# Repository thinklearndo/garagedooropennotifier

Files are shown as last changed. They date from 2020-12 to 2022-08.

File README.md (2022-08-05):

# garagedooropennotifier
A nodemcu project to notifiy users when the garage door gets left open.

For assembling the kit, see the [HardwareAssembly](https://github.com/thinklearndo/garagedooropennotifier/blob/main/HardwareAssembly.md)

For a 3d printable enclosure see the folder [3d_printer_files](https://github.com/thinklearndo/garagedooropennotifier/tree/main/3d_printer_files)

Then setup the software as specified in the [software setup](https://github.com/thinklearndo/garagedooropennotifier/blob/main/SoftwareSetup.md).

Kicad board files are in the boardfiles directory.

## OLED Raspberry Pi garage door state

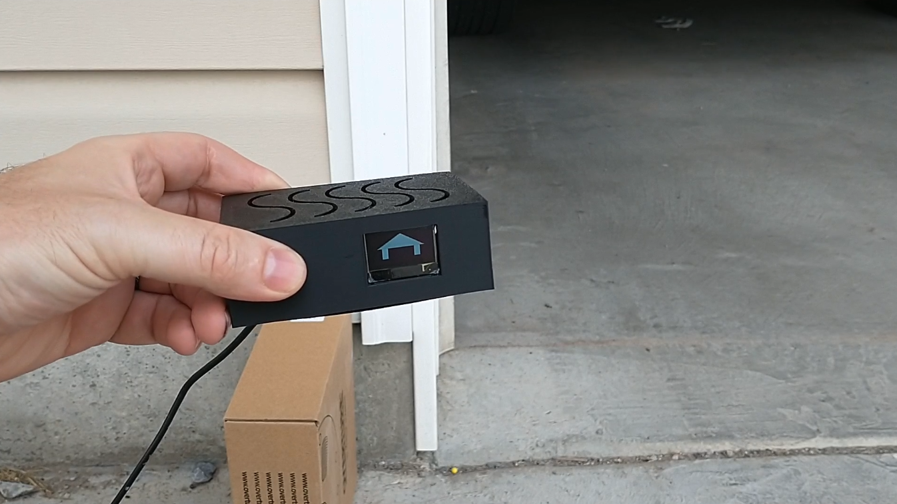
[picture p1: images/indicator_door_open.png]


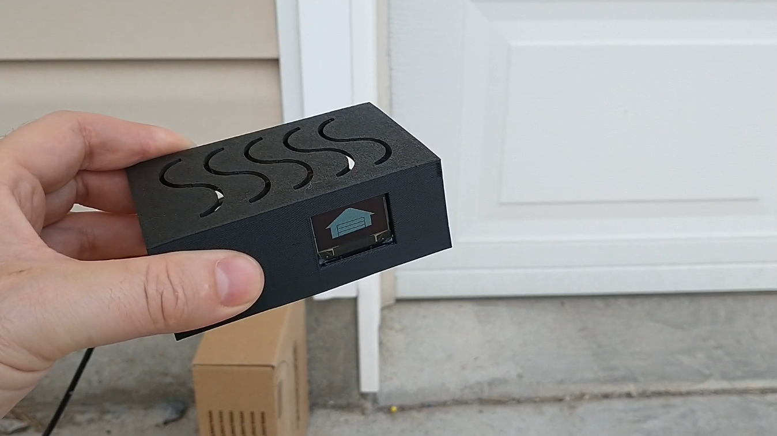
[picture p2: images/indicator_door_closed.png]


To setup a Raspberry Pi + OLED garage door state indicator, check out the [indicator setup document](docs/oledsetup.md).

[See it in action.](https://youtu.be/mj3vsc2727k)

## Troubleshooting

To verify the nodejs server is working correctly, send a get request using a web browser to the server itself, by doing something like:
```
http://<nodejs server ip address>:3000/garageAlert?doorState=1&doorId=0
```
where ```<nodejs server ip address>``` is the address of the server running the nodejs program.

The web browser should have this kind of response:
```
garage door alert received
```
Then after 5 minutes has passed an email should be sent to the specified email address.

If the web browser doesn't get the expected response, verify the ip address of the server and that the nodejs program is running.

If an email is not sent, verify the email settings in the app.js file.

To verify the nodemcu is working correctly, take the cover off and remove a battery to power it off. Then with the garage door closed, insert the battery but leave the cover off. Open the garage door enough that the device is horizontal. Watch the led indicator for the nodemcu, it should blink blue to show it has turned on. Check the console for the nodejs server, there should be a log with this message:
```
garage alert request received
```

If the nodemcu does not turn on, check that the tilt switch is installed correctly.

If the nodemcu does turn on but no message is logged, check the wifi settings and ip address of the firmware that was uploaded to nodemcu.

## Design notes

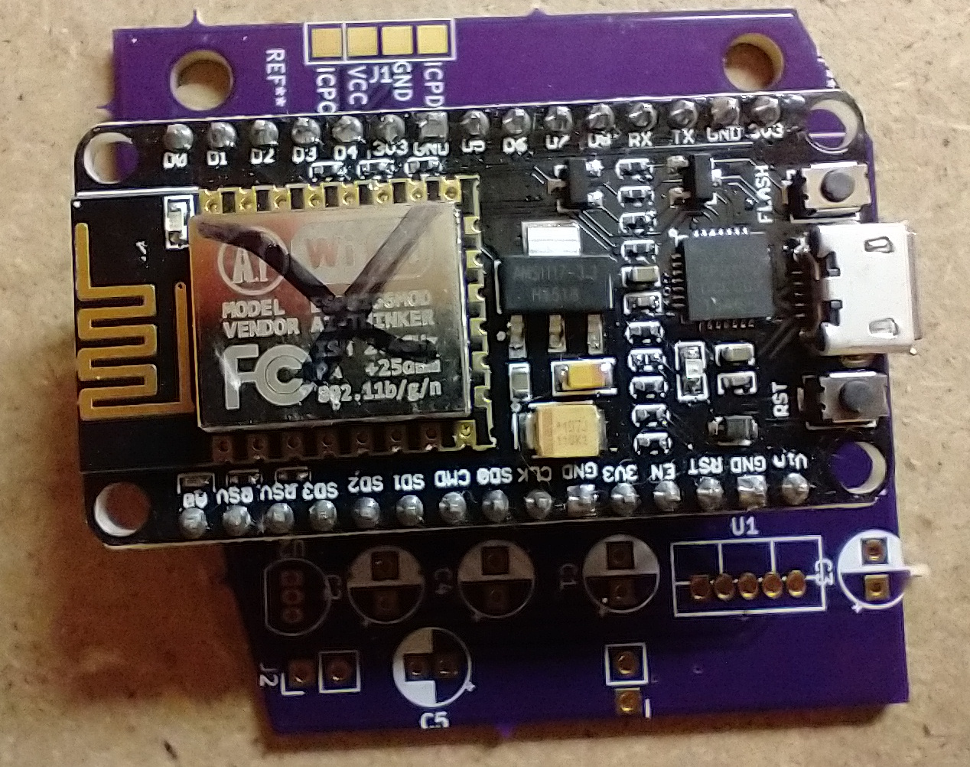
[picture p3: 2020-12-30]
images/nodemcu_inserted.jpg

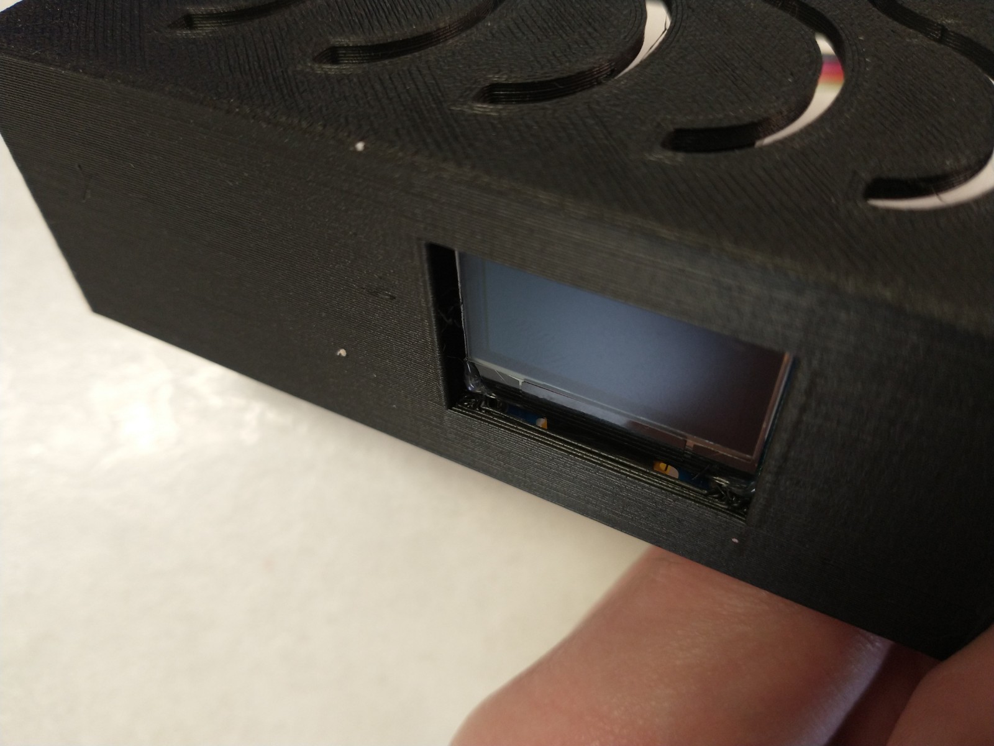
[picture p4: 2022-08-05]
images/oled_front.jpg

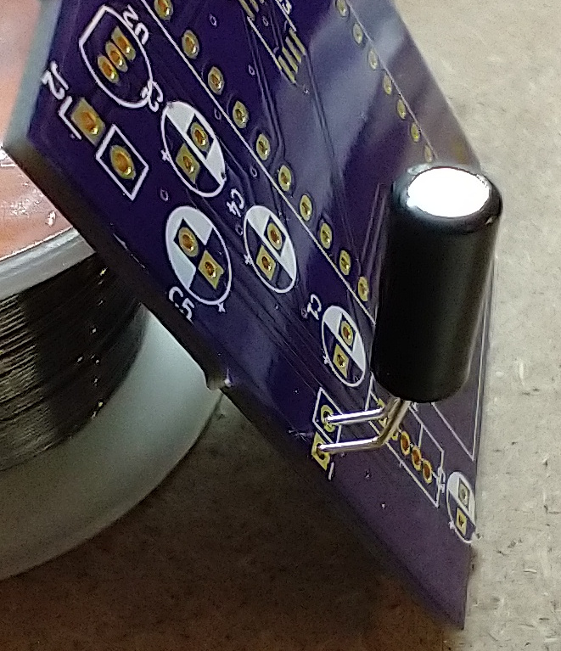
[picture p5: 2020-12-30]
images/tilt_switch_45.jpg

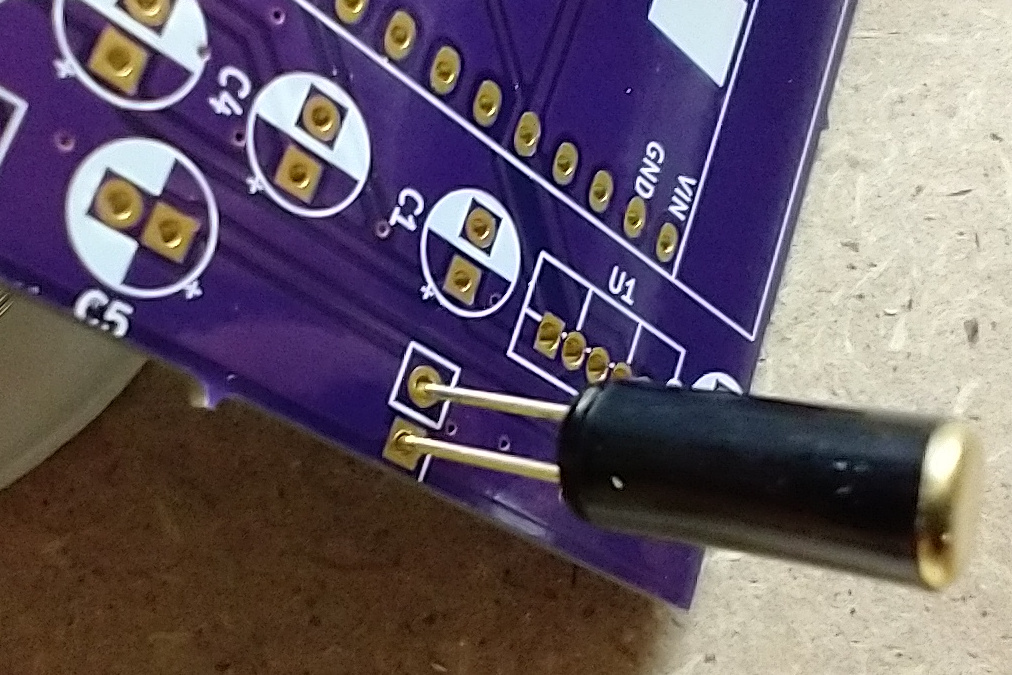
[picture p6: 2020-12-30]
images/tilt_switch_orientation.jpg

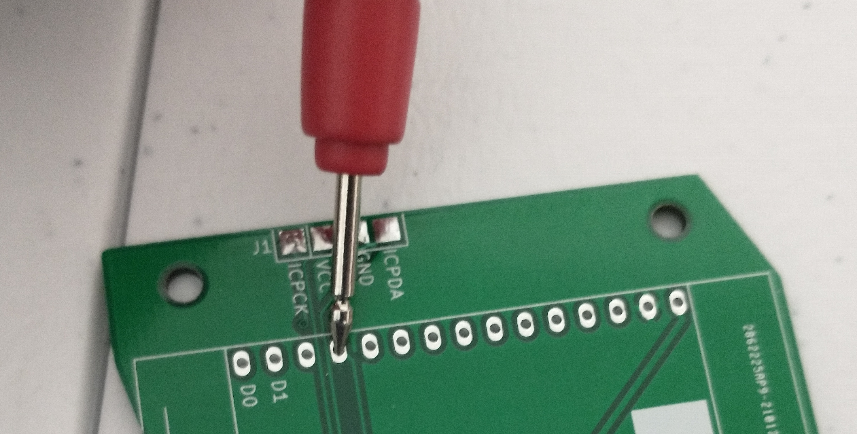
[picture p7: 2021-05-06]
images/positive_pin_4.jpg

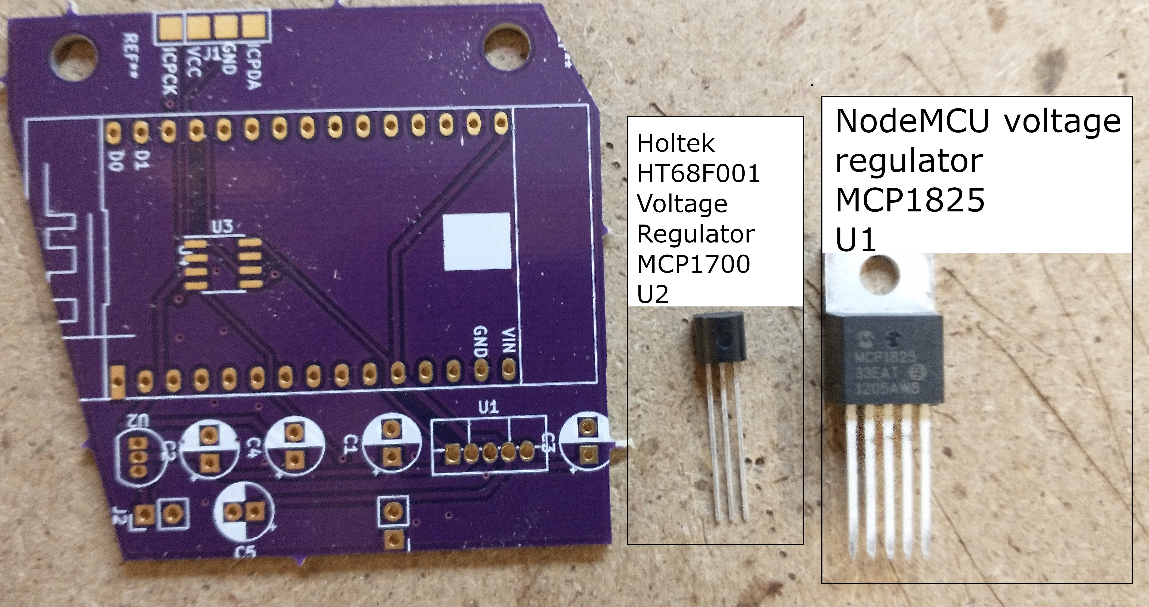
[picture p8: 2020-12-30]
images/voltage_regulators.jpg

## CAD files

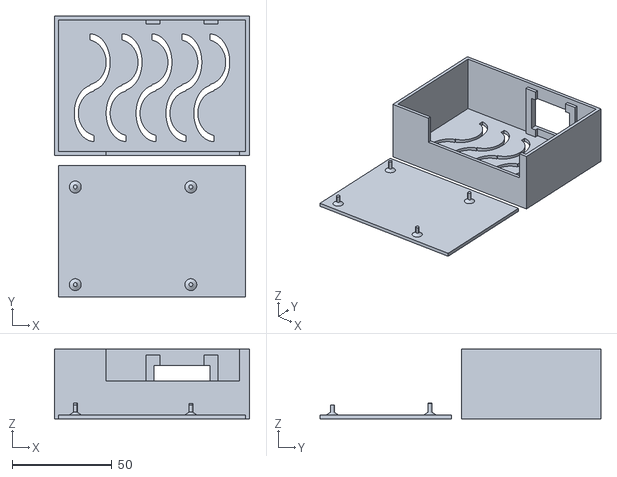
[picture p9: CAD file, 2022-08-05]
3d_printer_files/pi_oled_case_top_and_bottom.stl
98.0 x 141.0 x 35.0

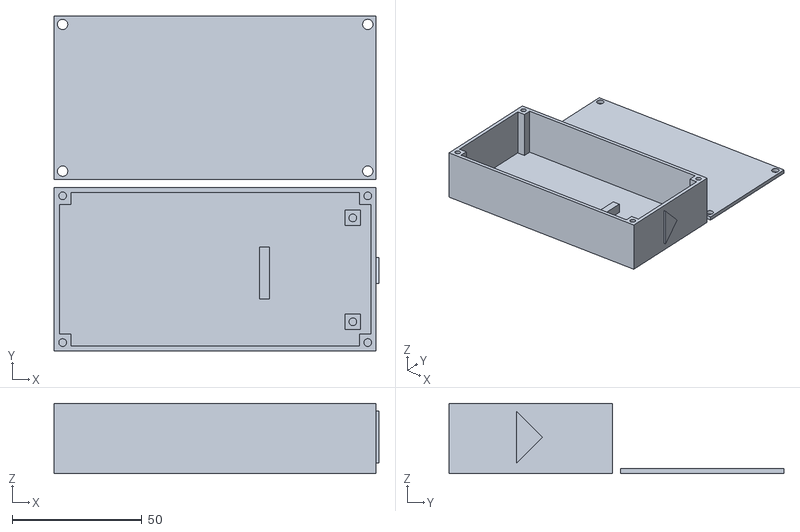
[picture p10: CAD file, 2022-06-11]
3d_printer_files/garagedoor box v1_withArrow.stl
125.0 x 129.0 x 27.0

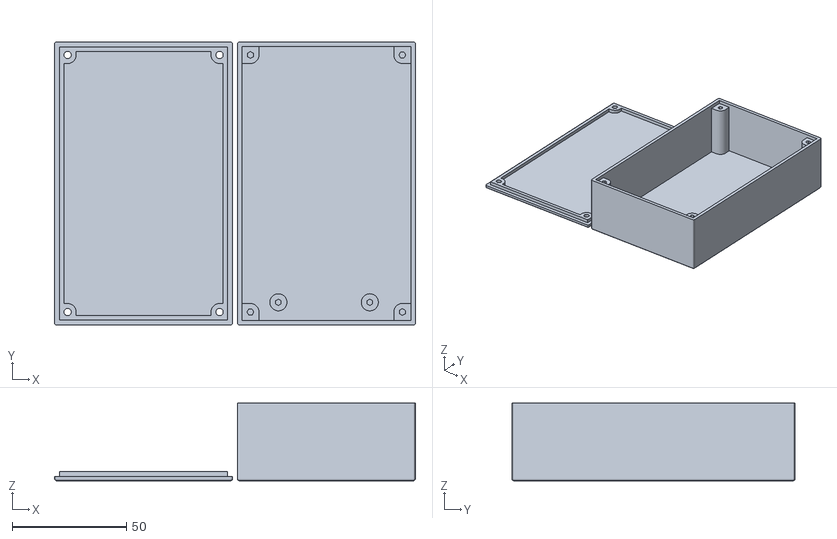
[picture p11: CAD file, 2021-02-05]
3d_printer_files/project_box_screws_garageDoorOpenNotifier.stl
158.0 x 124.0 x 34.0

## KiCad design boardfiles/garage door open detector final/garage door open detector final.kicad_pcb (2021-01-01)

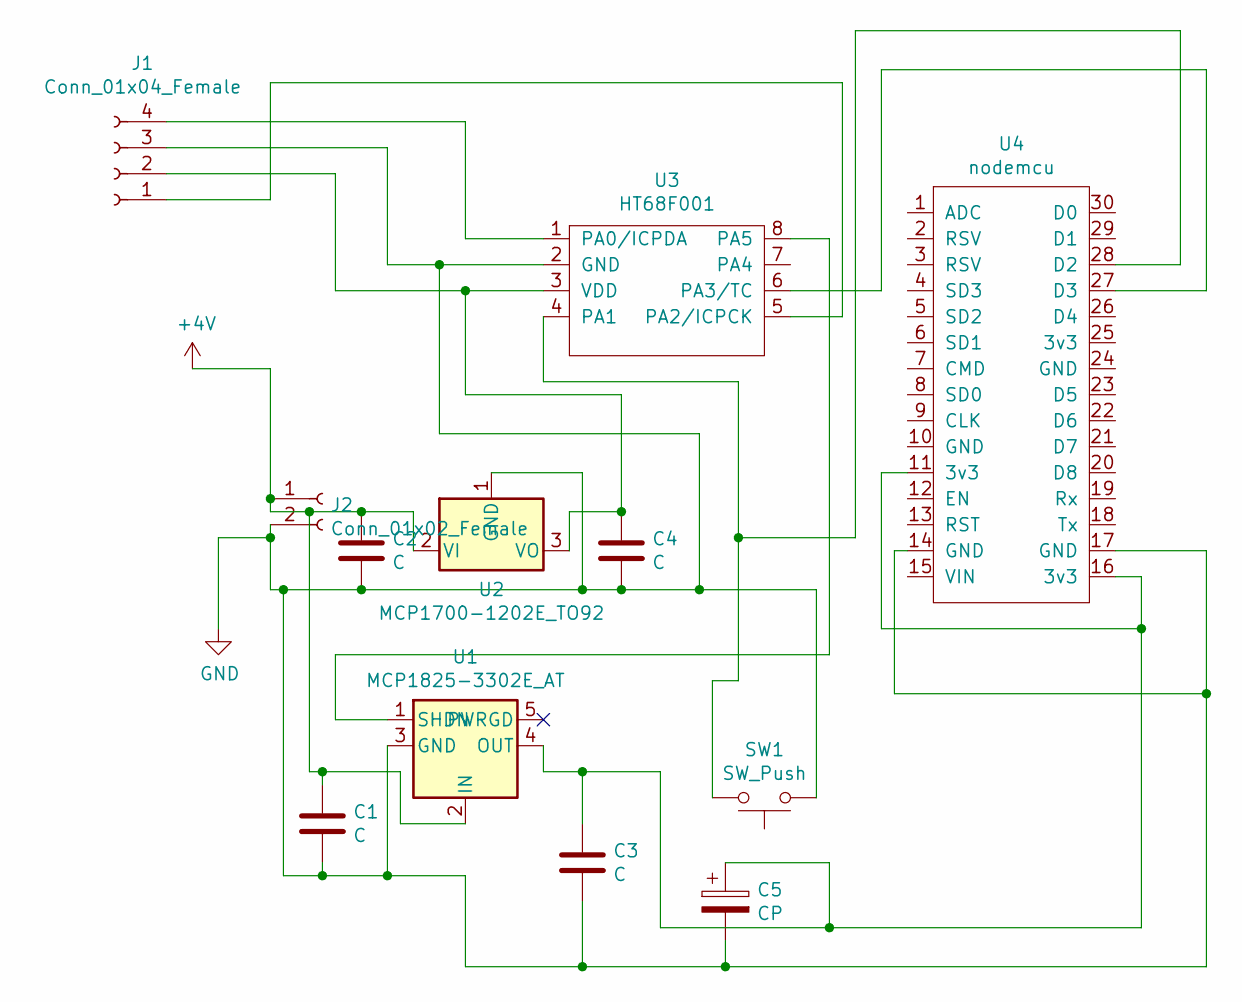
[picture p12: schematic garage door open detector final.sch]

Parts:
C1, C2, C3, C4: C; CP_Radial_D5.0mm_P2.50mm
C5: CP; CP_Radial_D5.0mm_P2.00mm
J1: Conn_01x04_Female; 4_pin_2.54pitch
J2: Conn_01x02_Female; PinHeader_1x02_P2.54mm_Vertical
SW1: SW_Push; PinHeader_1x02_P2.54mm_Vertical
U1: MCP1825-3302E_AT; TO-220F-5_Vertical
U2: MCP1700-1202E_TO92; TO-92_Inline
U3: HT68F001; SOIC-8_3.9x4.9mm_P1.27mm
U4: nodemcu; DIP-30_900_ELL

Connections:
+4V: C1.1, C2.1, J2.1, U1.2 (IN), U2.2 (VI)
GND: C1.2, C2.2, C3.2, C4.2, C5.2, J1.3, J2.2, SW1.1, U1.3 (GND), U2.1 (GND), U3.2 (GND), U4.14 (GND), U4.17 (GND)
unnamed: C3.1, C5.1, U1.4 (OUT), U4.11 (3v3), U4.16 (3v3)
unnamed: C4.1, J1.2, U2.3 (VO), U3.3 (VDD)
unnamed: J1.1, U3.5 (PA2/ICPCK)
unnamed: J1.4, U3.1 (PA0/ICPDA)
unnamed: SW1.2, U3.4 (PA1), U4.28 (D2)
unnamed: U1.1 (SHDN), U3.8 (PA5)
unnamed: U3.6 (PA3/TC), U4.27 (D3)

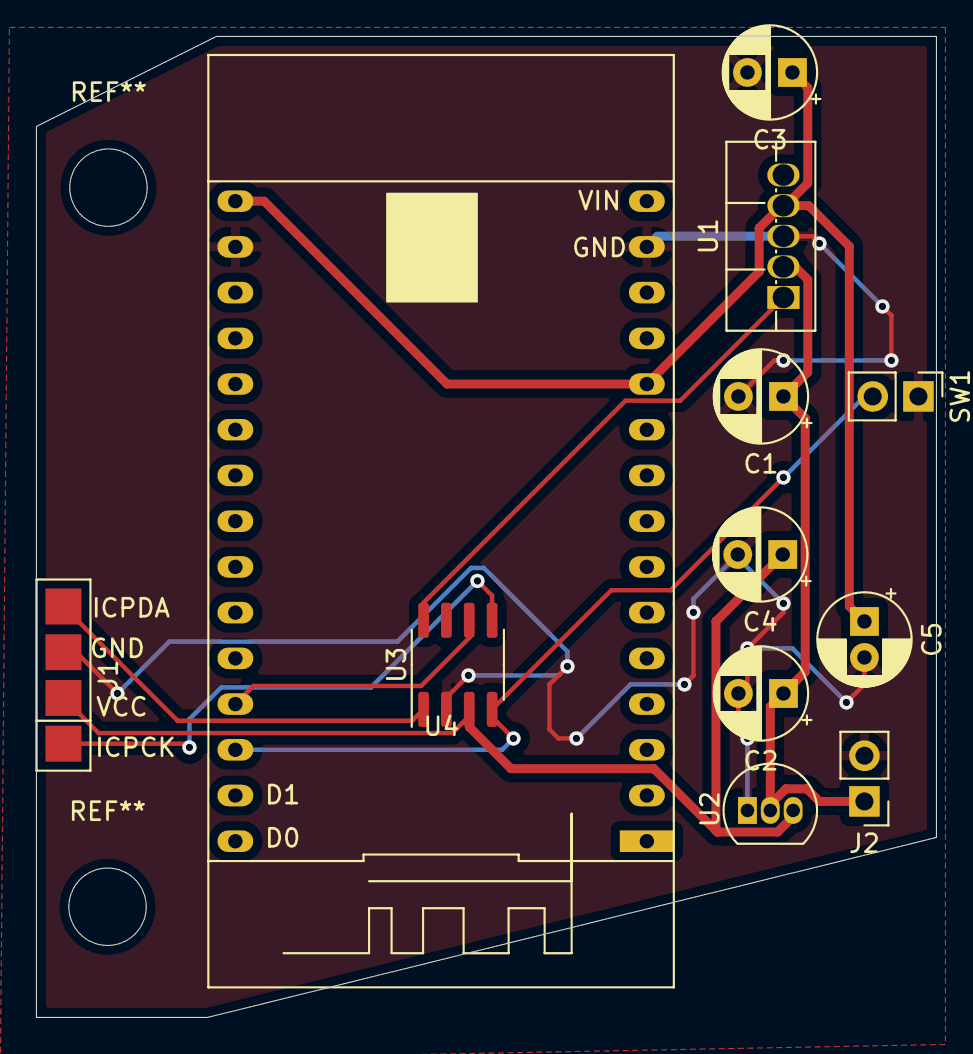
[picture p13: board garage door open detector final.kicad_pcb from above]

Board: 2 copper layers, 50.0 x 54.5 mm, 12 parts (0 on the bottom side), 9 nets.

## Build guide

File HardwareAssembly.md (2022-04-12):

# Hardware Assembly

## Additional items needed.

Phillips screw driver

3x AA batteries

## Program and insert the NodeMCU

Upload the program for the NodeMCU according to the [software instructions](https://github.com/thinklearndo/garagedooropennotifier/blob/main/SoftwareSetup.md). Then insert it into the headers.

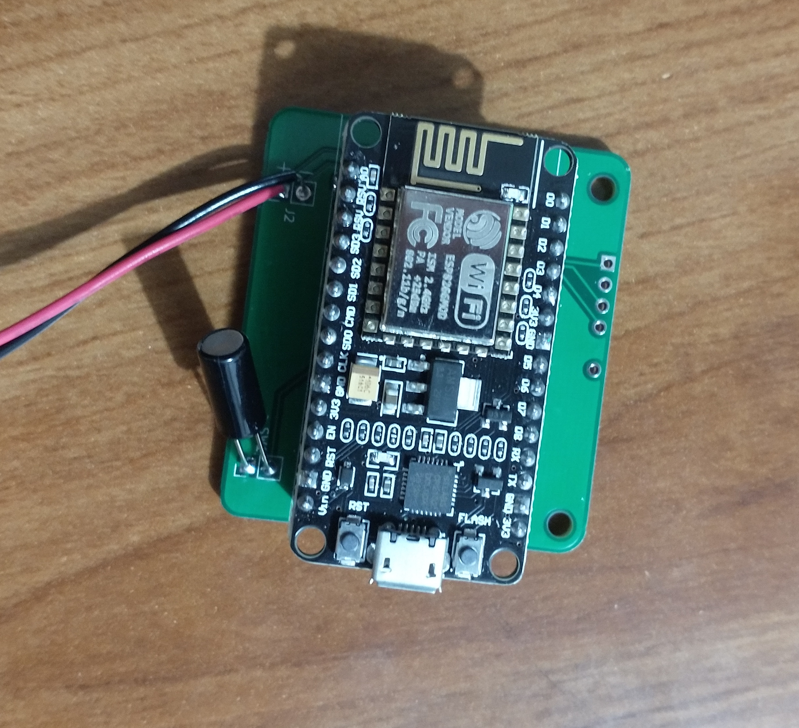
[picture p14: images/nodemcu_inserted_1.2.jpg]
Nodemcu inserted


## Screw the circuit board into the case

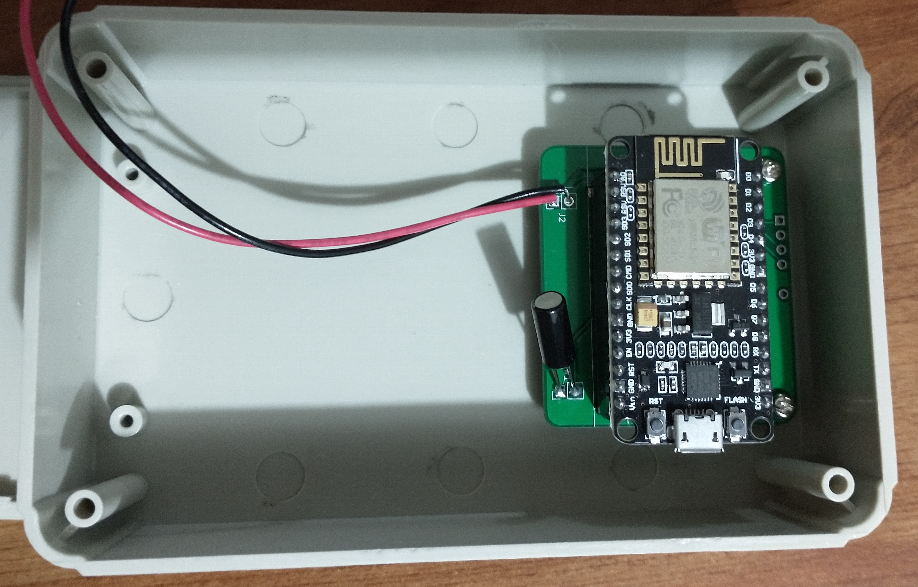
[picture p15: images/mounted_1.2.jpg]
board screwed in


## Put hook and latch material on battery holder and inside case

Get the smaller patch of hook and latch material to put one side on the back of the battery holder and the other side inside the case to the left of the circuit board. Press the battery holder firmly into the box and make sure the hook and latch material is connected well.

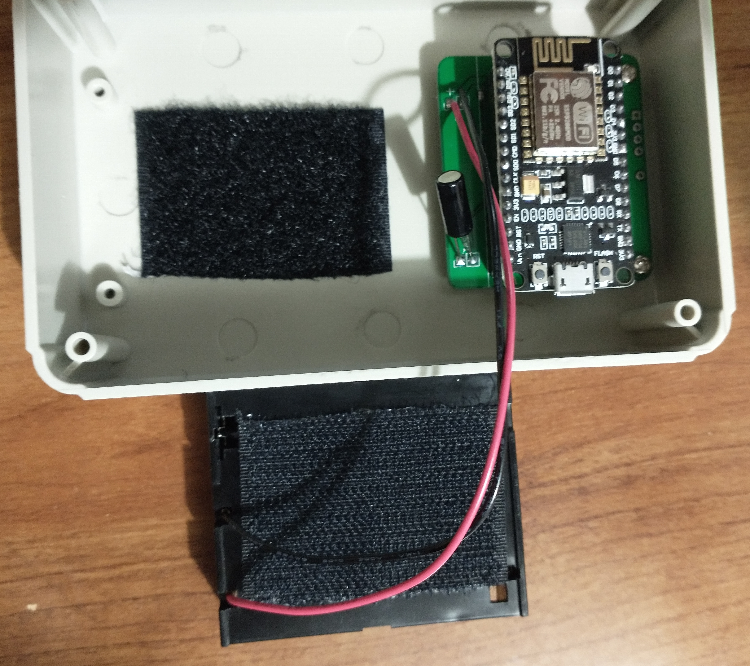
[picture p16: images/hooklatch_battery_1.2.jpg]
hook and latch on battery holder


## Final assembly

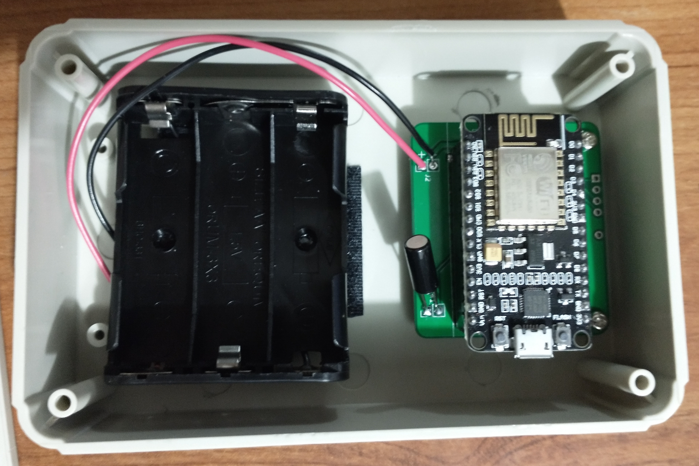
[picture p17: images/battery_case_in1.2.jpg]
all put together


When mounting it to the garage door, make sure the orientation of the box is correct. The top of the tilt switch should be pointed up.

Also, the box needs to be mounted similar to the picture. The back of the pcb needs to be against the garage door and the tilt switch needs to be facing into the garage.

When the garage door is open, the tilt switch needs to be towards the ground. Otherwise the tilt switch won't work correctly and it will always say the garage door is closed.

Get the large patch of hook and latch material and place one side on the back of the box and the other at the top of the garage door. Firmly press the case against the hook and latch material to make sure it has a good connection. Insert AA batteries and screw on the lid.

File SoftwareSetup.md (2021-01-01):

# Softare Setup

## Server setup with nodejs

The server will need to have nodejs installed. The app.js file is located in the nodejs folder. cd into that folder and install the dependencies:

```
npm install
```

You will need to open app.js with a text editor and update the following values:

```
//////
// needs configured
// tested with service: 'gmail'
// user is gmail email address
// pass is gmail password that has been created
//////
var transporter = nodemailer.createTransport({
  service: 'gmail',
  auth: {
    user: 'YOUREMAILADDRESS@gmail.com',
    pass: 'YOURAPPPASSWORD'
  }
});

////
// needs configured
// from is your email address
// to is the email address you want to send the alert
// subject and text can be changed.
////
var mailOptions = {
  from: 'YOUREMAILADDRESS@gmail.com',
  to: 'TARGETEMAILADDRESS@gmail.com',
  subject: 'The garage door got left open...',
  text: 'Go close the garage door!!!'
};
```

If you are using gmail, you will need to add an app password. See here for info: https://support.google.com/accounts/answer/185833?hl=en.

That app password will need to entered into the pass field.

Then start the server with ```nodejs app.js```

## esp8266 firmware

In the esp8266Code folder is the garageDoorESP8266.ino file for Arduino. Install the Arduino studio: https://www.arduino.cc/en/software, then add the eps8266 core for arduino: https://github.com/esp8266/Arduino#installing-with-boards-manager

Open the garageDoorESP8266.ino file in Arduino studio.

There are a couple of fields that will need to be configured:

```
/////////////////////////////
// ITEMS THAT NEED CONFIGURED
/////////////////////////////

String serverIp = "192.168.2.101"; // ip address of the nodejs server
int doorId = 0; // Id of the door that got left open. For one door just leave it 0.

String wifiNetworkName = "WIFINETWORKNAME"; // network to connect to. Can't be a 5ghz wifi network.
String wifiNetworkPassword = "WIFIPASSWORD"; // wifi password
```

You will need the ip address of the server you setup earlier. Set that in the serverIp field.
Set the wifi network name and password.

Then compile and upload the code to the Nodemcu. 
An example for doing this can be found here: https://create.arduino.cc/projecthub/najad/using-arduino-ide-to-program-nodemcu-33e899

Once the code is uploaded, the Nodemcu is ready to be inserted into the board, as shown in the [HardwareAssembly](https://github.com/thinklearndo/garagedooropennotifier/blob/main/HardwareAssembly.md) document.

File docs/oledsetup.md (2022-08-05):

# Parts needed

1x raspberry pi, with operating OS and wifi

1x hot glue gun

1x OLED

4x female to femal jumper wires

1x garage door left open notifier setup to point to the raspberry pi

1x raspberry pi oled case [Stl here](../3d_printer_files/pi_oled_case_top_and_bottom.stl).

# Assembly for OLED garage state indicator

Print out the case pieces.

Insert the oled into the case, use hot glue to hold it. Wires go along the top of the lid.

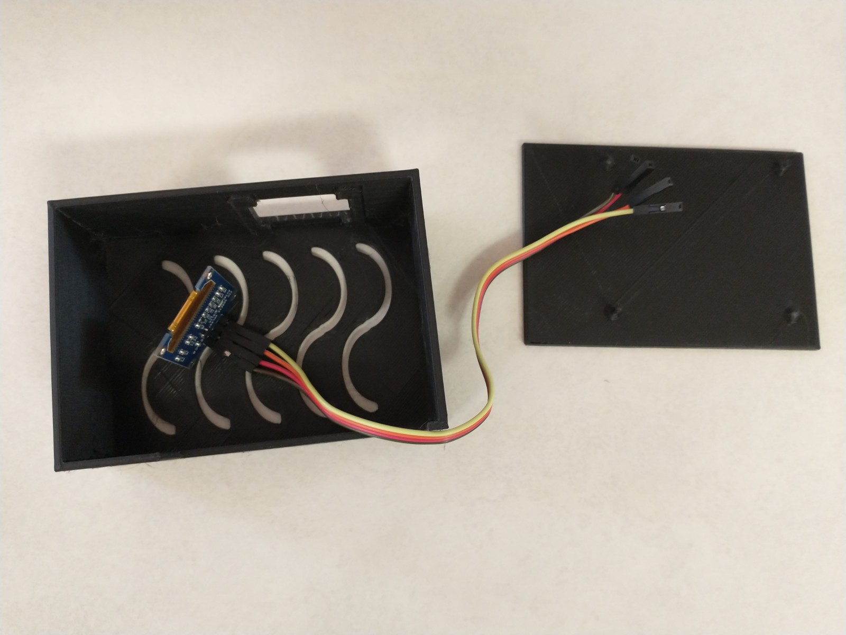
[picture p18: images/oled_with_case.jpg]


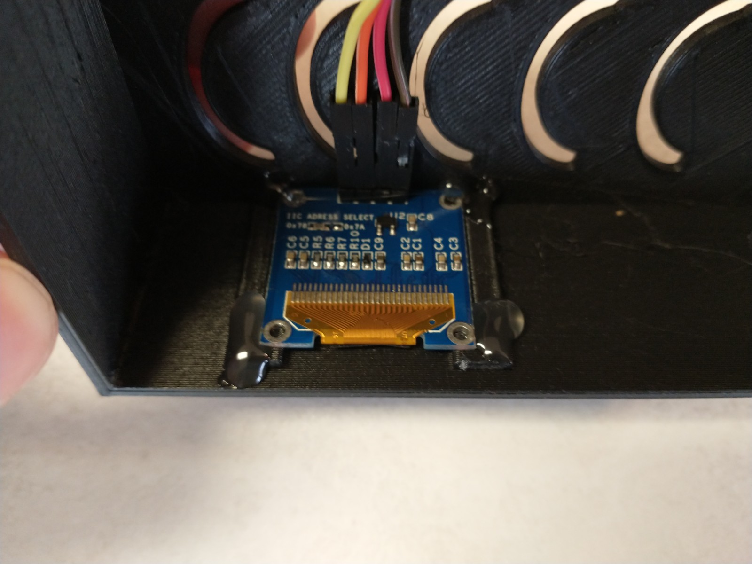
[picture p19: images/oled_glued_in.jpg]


Place the raspberry pi on the bottom. I didn't care if it moved around in there, so I didn't glue it in, but you can if you want it.

Connect the wires for the oled to the raspberry pi, according to the diagram.

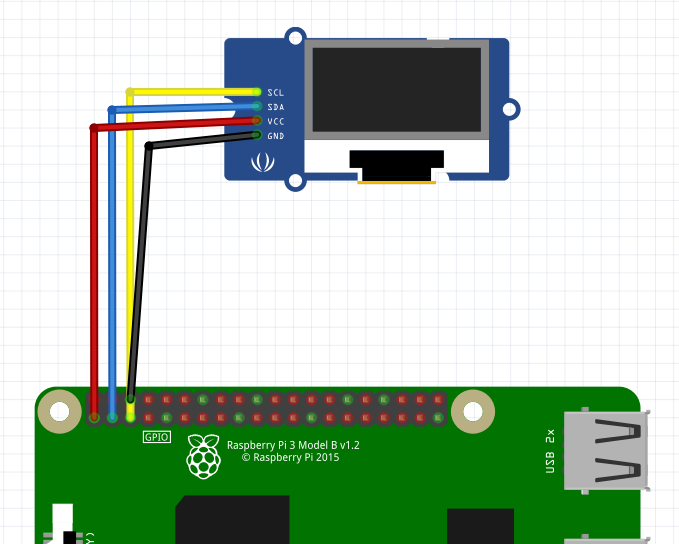
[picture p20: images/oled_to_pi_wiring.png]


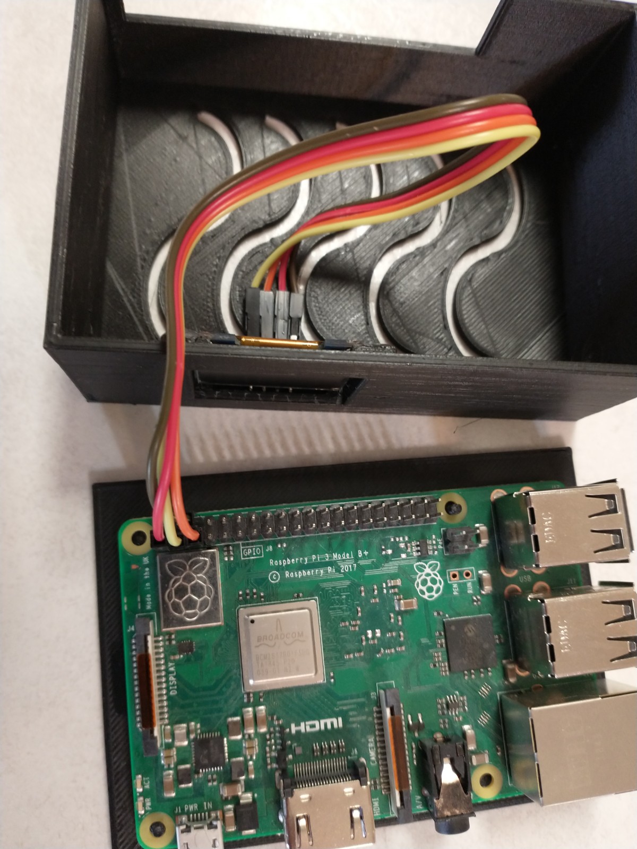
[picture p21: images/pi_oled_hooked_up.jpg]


Put the lid on the bottom piece, they should just snap together.

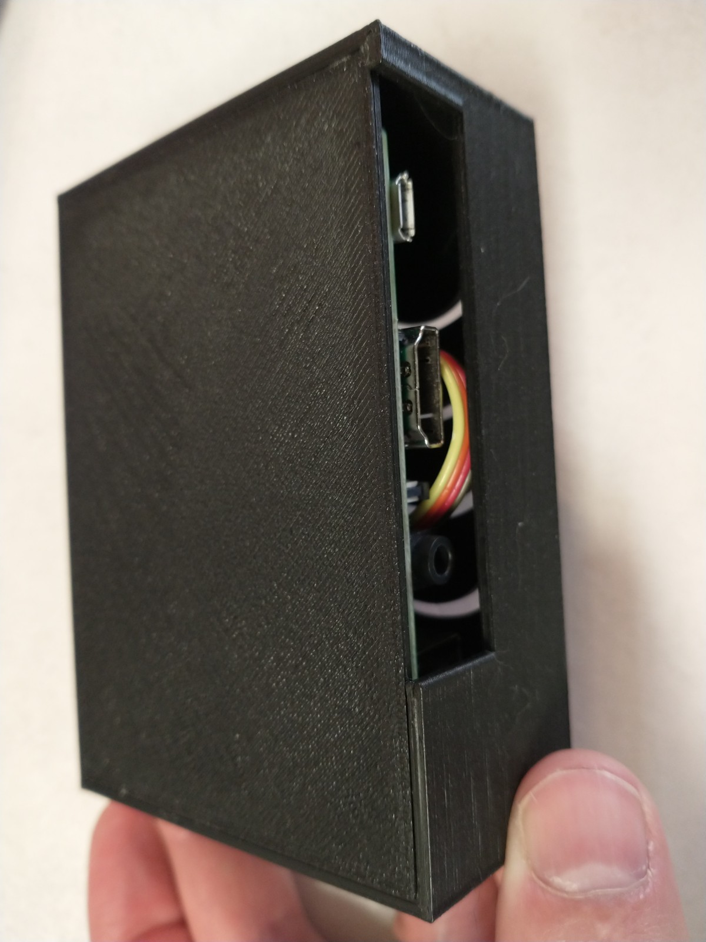
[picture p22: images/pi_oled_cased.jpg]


Plug in power for the raspberry pi and let it start up.

One the Raspberry pi, install nodejs and git if needed: ```sudo apt install nodejs git```

Checkout the repo: ``` git checkout https://github.com/thinklearndo/garagedooropennotifier```

Install dependencies: ``` cd garagedooropennotifier/nodejs && npm install```

Start the nodejs server: ```nodejs app.js```

# Verifying operation

Open a web browser on another computer and go to this URL: ```http://<ip address of raspberry pi>/garageAlert?doorState=1&doorId=0```. The OLED should show the open garage door image.

Then to test that it will show the closed image, go to this URL ```http://<ip address of raspberry pi>/garageAlert?doorState=0&doorId=0```.

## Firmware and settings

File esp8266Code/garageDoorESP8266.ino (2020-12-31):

#include <Arduino.h>

#include <ESP8266WiFi.h>

#include <ESP8266HTTPClient.h>

#include <WiFiClient.h>
/////////////////////////////
// ITEMS THAT NEED CONFIGURED
/////////////////////////////

String serverIp = "192.168.2.101"; // ip address of the nodejs server
int doorId = 0; // Id of the door that got left open. For one door just leave it 0.

String wifiNetworkName = "WIFINETWORKNAME"; // network to connect to. Can't be a 5ghz wifi network.
String wifiNetworkPassword = "WIFIPASSWORD"; // wifi password


// end configuration items


int switchPin = D2;
int ht68f001Pin = D3;

void sendAlert() {

  WiFi.begin(wifiNetworkName, wifiNetworkPassword);

  int wifiWaitCount = 0;
  while ( WiFi.status() != WL_CONNECTED && wifiWaitCount < 10) {
    Serial.printf("waiting for wifi connection...\n");
    Serial.flush();
    wifiWaitCount++;
    delay(1000);
  }

  int doorState = 0;

  if (isDoorOpen()) {
    doorState = 1;
  }

  if (WiFi.status() == WL_CONNECTED) {

    WiFiClient client;

    HTTPClient http;

    Serial.print("[HTTP] begin...\n");
    if (http.begin(client, "http://" + serverIp + ":3000/garageAlert?doorState=" + doorState + "&doorId=" + doorId)) {  // HTTP


      Serial.print("[HTTP] GET...\n");
      // start connection and send HTTP header
      int httpCode = http.GET();

      // httpCode will be negative on error
      if (httpCode > 0) {
        // HTTP header has been send and Server response header has been handled
        Serial.printf("[HTTP] GET... code: %d\n", httpCode);

        // file found at server
        if (httpCode == HTTP_CODE_OK || httpCode == HTTP_CODE_MOVED_PERMANENTLY) {
          String payload = http.getString();
          Serial.println(payload);
        }
      } else {
        Serial.printf("[HTTP] GET... failed, error: %s\n", http.errorToString(httpCode).c_str());
      }

      http.end();
    } else {
      Serial.printf("[HTTP} Unable to connect\n");
    }
  }
  else {
    Serial.println("Failed to connect to WIFI!");
  }

  WiFi.disconnect();
}

bool isDoorOpen() {
  int pinState = digitalRead(switchPin);

  if (pinState == HIGH) {
    //debounce is done by ht68f001
    return true;
  }

  return false;
}

void setup() {

  pinMode(ht68f001Pin, OUTPUT);
  digitalWrite(ht68f001Pin, HIGH);

  pinMode(switchPin, INPUT_PULLUP);

  Serial.begin(115200);

  Serial.println("== turned on! ==");

  sendAlert();

  Serial.println("telling ht68f001 to turn us off");

  digitalWrite(ht68f001Pin, LOW);

  delay(10000);

}

void loop() {
// doesn't do anything here


}

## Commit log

2020-12-30 Create AssemblyNotes.md
    getting it started
2021-01-01 adding kicad board files
    [garage door open detector final.kicad_pcb, garage door open detector final.sch]
2021-02-05 uploaded 3d printable enclosure that should work
    [project_box_screws_garageDoorOpenNotifier.stl]
2021-02-05 Update README.md
    updated to include a link to the 3d printer files
2021-03-10 Add files via upload
    showing new power connection
2021-03-10 Update HardwareAssembly.md
    showing new board battery connection
2021-03-25 Update HardwareAssembly.md
    adding more info on mounting it to the garage door.
2022-06-11 Adding a 3d printable box with orientation arrow.
    [garagedoor box v1_withArrow.stl]
2022-08-05 Add files via upload
    adding oled assembly pics
2022-08-05 Add files via upload
    adding the pi oled case parts
    [pi_oled_case_top_and_bottom.stl]
2022-08-05 Add files via upload
    adding wiring diagram
2022-08-05 Delete oled_to_pi_wiring.jpg
    and wrong pin for ground
2022-08-05 Add files via upload
    correct wiring
